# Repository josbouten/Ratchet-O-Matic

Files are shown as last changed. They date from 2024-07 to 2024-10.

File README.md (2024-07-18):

# Ratchet-O-Matic

This is Ratchet-O-Matic, a clock multiplier and clock divider.

While watching a video by Gary P. Hayes using a clock multiplier to ratchet some notes and playing with a Hydra synth (which has a knob for ratcheting on the front panel!) at my friend Macross' house I got inspired to make my own module that can ratchet, which I will call a ratcheteer. It has a second mode in which it can divide gate pulses (skip notes).

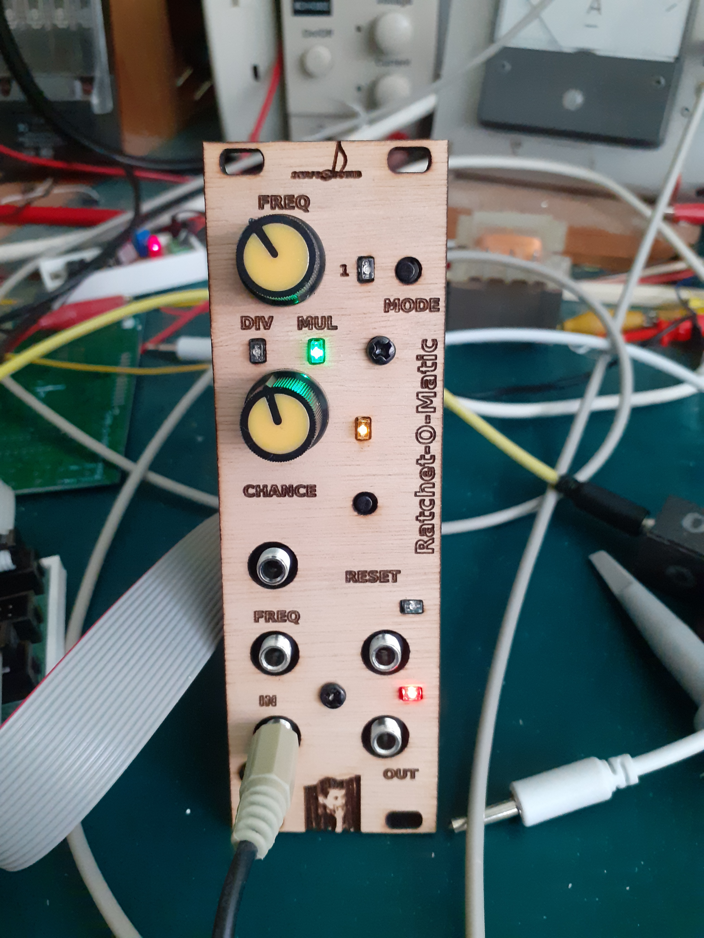
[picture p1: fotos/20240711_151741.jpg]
Ratchet-O-Matic ratcheteer


In this demo you can see and hear hand controlled ratcheting and ratcheting using a B960 sequencer to control the ratchet frequency and the odds to ratchet.
Also a short demo of dividing gates is shown.

https://www.youtube.com/watch?v=JYEgaoM7ovk

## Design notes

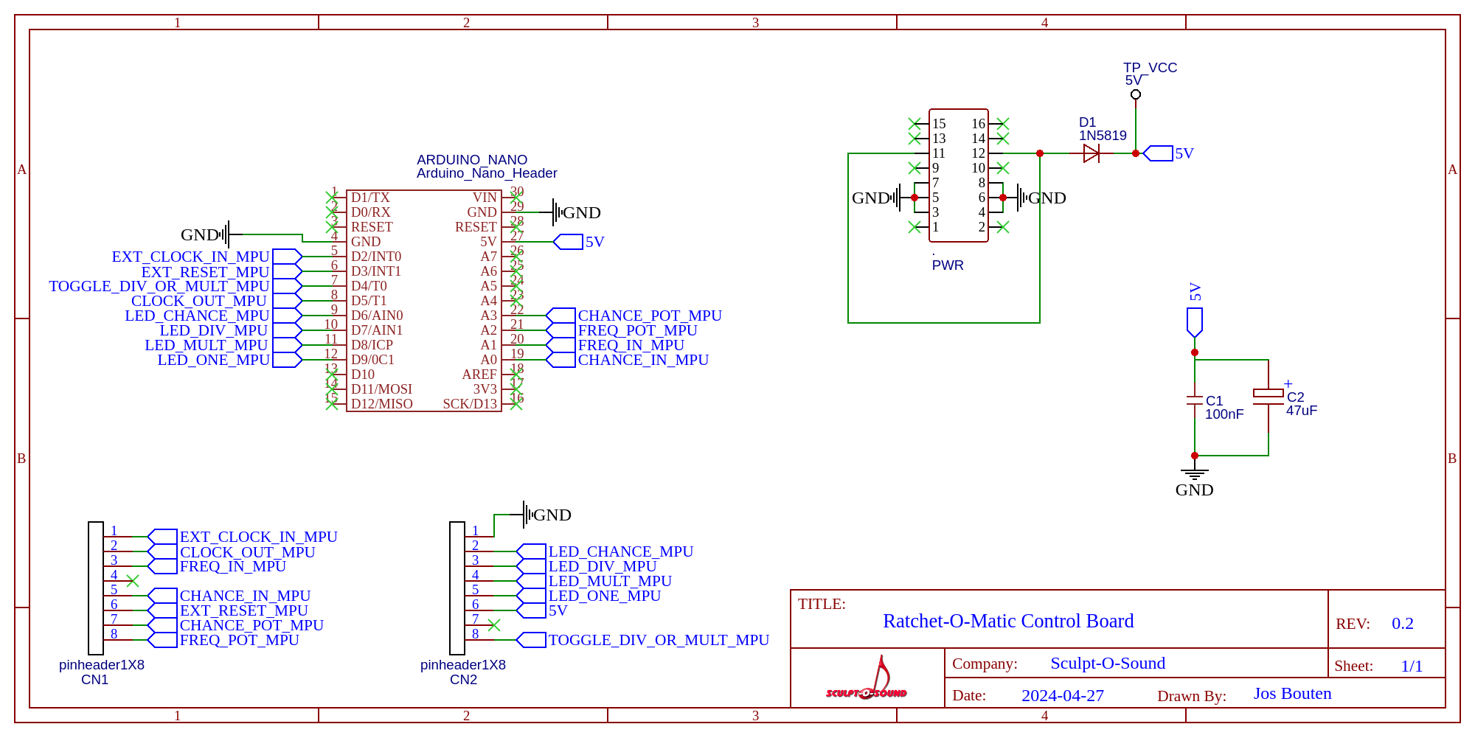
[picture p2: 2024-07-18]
schematics/Schematic_Ratchet-O-Matic-single-control-board-v0.2.png

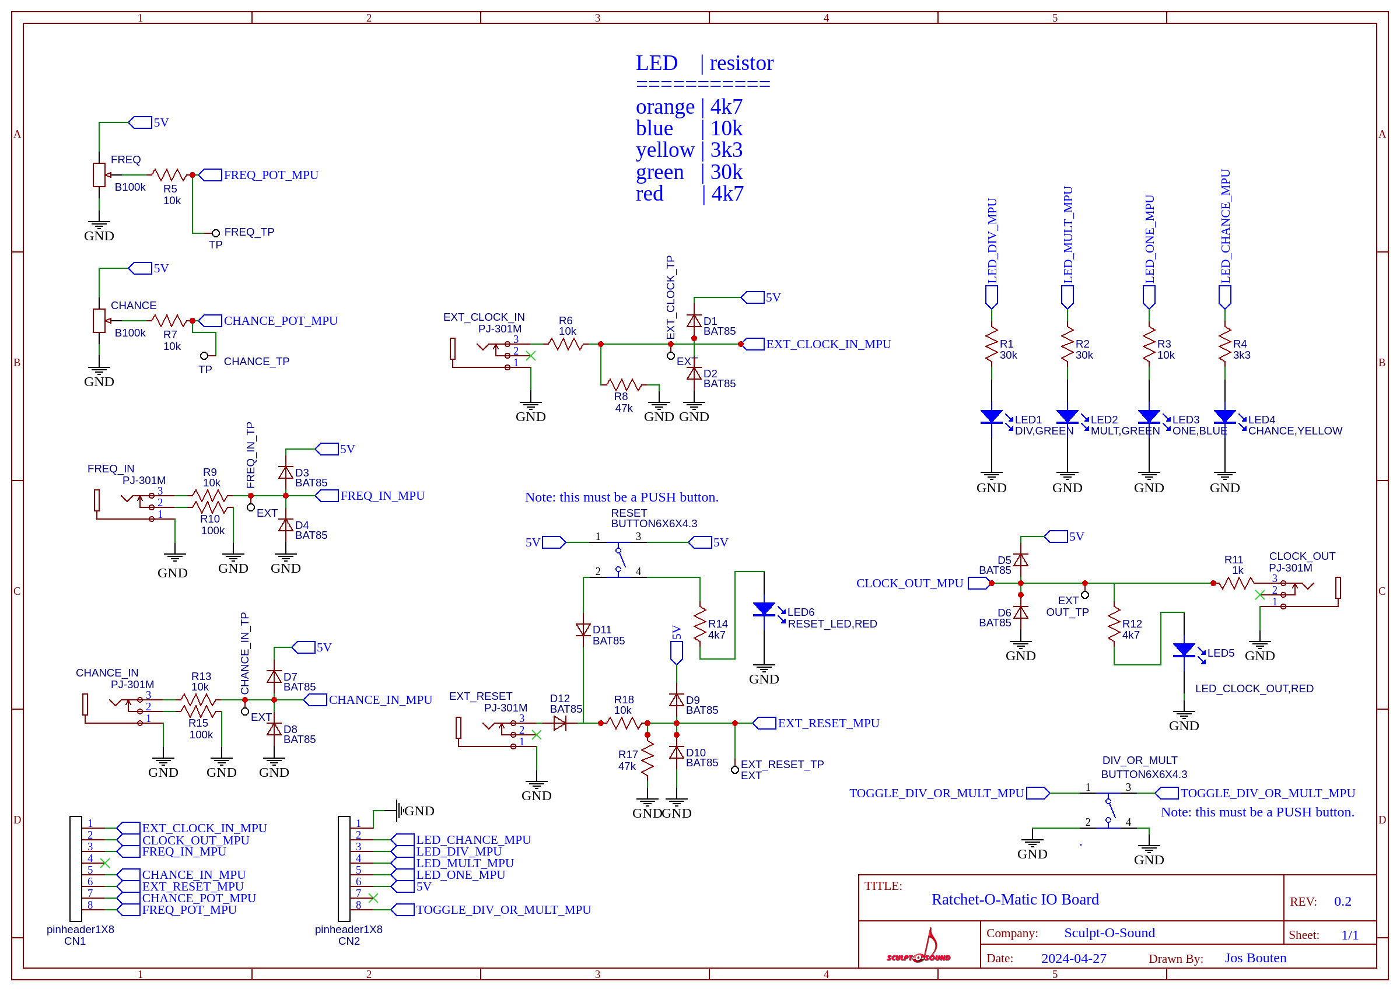
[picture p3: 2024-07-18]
schematics/Schematic_Ratchet-O-Matic-single-IO-board-v0.2.png

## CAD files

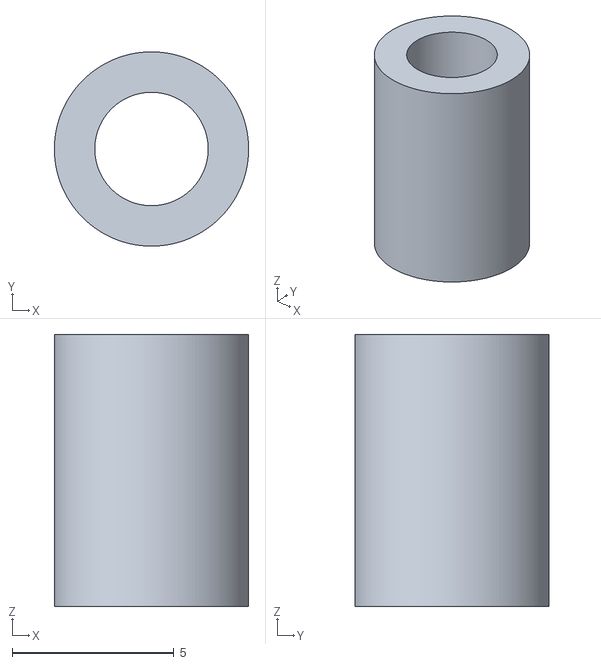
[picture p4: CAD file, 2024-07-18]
3D/afstandsbus_01.stl
6.00 x 6.00 x 8.40

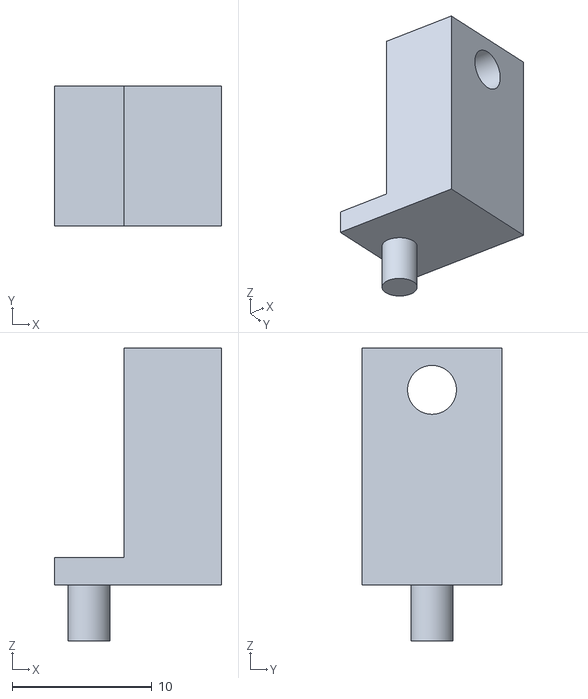
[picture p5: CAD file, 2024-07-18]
3D/bracket_05.stl
12.0 x 10.0 x 21.0

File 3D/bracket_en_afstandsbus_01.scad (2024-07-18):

// Steunbeugel voor de PCBs van de Ratchet-O-Matic.abs

$fn = 160;

as_lengte = 4; // mm.

opzet_blok_hoogte = 15;
opzet_blok_x = 7; 
opzet_blok_y = 10;
basis_height = 2;

module as() {
    diameter = 3.0;
    cylinder(h=as_lengte, r = diameter / 2, center=true);
}

module basis_links() {
    x = 12;
    y = 10;   
    cube([x, y, basis_height], center = true);
}


module opzet_blok() {
    cube([opzet_blok_x, opzet_blok_y, opzet_blok_hoogte], center = true);
}

module boorgat_links() {
    #translate([3, 0, 0]) rotate([0, 90, 0]) cylinder(h=opzet_blok_x, r=3.5 / 2.0, center = true);
}

module blokje_links() {
    translate([0, 0, as_lengte / 2]) as();
    translate([3.5, 0, as_lengte + basis_height / 2]) basis_links();
    x_verplaatsing = 6;
    translate([x_verplaatsing, 0, as_lengte + basis_height + opzet_blok_hoogte / 2]) opzet_blok();
}

module bracket() {
    difference() {
        blokje_links();
        boorgat_hoogte = as_lengte + basis_height + opzet_blok_hoogte - 3;
        echo("boorgat hoogte:", boorgat_hoogte);
        translate([3, 0, boorgat_hoogte]) boorgat_links();
    }
}

module afstandsbus() {
    difference() {
        cylinder(8.4, 6 / 2, 6 / 2);
        cylinder(8.4, 3.5 / 2, 3.5 / 2);
    }
}

module alles(a = 0, b = 0) {
    if (a == 1) {
        translate([20, 0, 0]) bracket();
    }
    if (b == 1) {
        afstandsbus();
    }
}

alles(1, 1);

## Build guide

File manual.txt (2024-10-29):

Ratchet-O-Matic
===============
There are 3 modes, DIV, MULT and MAX_MULT.
In DIV-mode the input gates are devided by a number.
This number is determined by the maximum value read from the FREQ-pot and the FREQ-CV input.
Whether any division is done depends on the highest value read from the CHANCE-pot and CHANCE CV-input.
This value is converted into a probability running from 0 to 1. A higher probability makes it more likely that
a gate signal will be generated.
The gate in frequency can be divide by 1, 2, 3, 4, 5, 6, 7, 8, 9 and 16.

In MULT-mode the input gates are multiplied by a factor 0, 1, 2, 3, 4 or 5.
This multiplication number is determined by the maximum value read from the FREQ-pot and the FREQ-CV input.
If the factor is 1 then the '1'-led will light up.

In MULT_MAX mode the number of ratchets varies at random from a minimum value set by the FREQ-knob
to a maximum value determined by the CV-input value.

Switching from DIV to MULT or DIV to MAX_MULT can be done by pressing the mode button once.
Switching from MAX_MULT to MULT and vv can be done in either mode by quickly double pressing the mode button.

Basic use of Ratchet-O-Matic
============================

0: make sure you have the following chain of modules prepared:
0a: an oscillator which produces a constant signal. Its pitch should be set. This oscillator is
0b: patched into a VCA (which has a gate input), which is
0c: patched into an amplifier with a speaker.
0d: prepare a clock source.

1: set the external clock to a slow pattern
   For beginners this makes it easier to discover the things Ratchet-O-Matic can do for you.
2a: connect the clock to the 'SHIFT'-input of the 960 sequencer,
2b: connect the clock output to the ‘clock in’ of the Ratchet-O-matic module,
2c: make sure the mode is set to ‘MUL’ (MULT-led is continuously lit) or 'MULT_MAX' (MULT-led will flash).
    MULT is the default mode when first switched on. After that the device will remember which
    state you last set it to.

3: connect the ‘gate out’ of Ratchet-O-Matic to the ‘gate’ of the VCA

4: choose the mode (MULT/DIV/MAX_MULT) using the mode button.

5: set a frequency with the FREQ-knob. Turned fully counterclockwise the frequency = 0,
   no gate signal pulse will be sent to the output.
   Turned fully clockwise, the frequency is 5 when in ratchet mode. In divide mode the frequency is 1/16
   The clock in frequency can be divide by 1, 2, 3, 4, 5, 6, 7, 8, 9 and 16 in DIV mode.
   The clock in frequency is multiplied by a factor 0, 1, 2, 3, 4 or 5. in (MAX_)MULT mode.
   When set to 1 the '1'-led will light up.

6: use the CHANCE-knob or connect a cv value to the chance-in input to set the odds that a ratchet or divided
   clock will be passed to the output. In MAX_MULT the chance pot and cv-value are ignored.

How to use Ratchet-O-Matic incombination with a 960 sequencer
=============================================================

0: make sure you have the following chain of modules prepared:
0a: an oscillator which produces a constant signal (either tone or noise),
0b: patched into a VCA (which has a gate input),
0c: patched into an amplifier with a speaker.
0d: prepare a clock source.

1: set the external clock to a slow pattern,

2a: connect the clock to the 'SHIFT'-input of the 960 sequencer,
2b: connect the clock output to the ‘clock in’ of the Ratchet-O-matic module,
2c: make sure the mode is set to ‘MUL’ = multiply, the LED should then light up,
That is the default mode, but the device will remember in what state you switched it off,
so you may have to set it to ‘MUL’,

3: connect the ‘gate out’ of Ratchet-O-Matic to the ‘gate’ of the VCA

4: Choose the MULT-mode using the mode button. The MULT-led should be lit continously.
   When the MULT-led is flashing you are in the MAX_MULT mode. Double click the button to
   return to the MULT mode.

5: press the “osc off” button of the 960. It should not run on its own oscillator,

6: connect a patch cable from the bottom row of the 960 to the ‘chance-in’ input of Ratchet-O-Matic,

7: connect a patch cable from the middle row of the 960 to the ‘freq-in’ input of Ratchet-O-Matic,

8: connect a patch cable from the top row of the 960 to the ‘V/Oct-in’ of the audio oscillator,

9a: set the bottom row chicken knob of the 960 to ‘X2’,
9b: set the pots of the bottom row of the 960 all far beyond the center position.
    This should set the odds for them to fire all the time high enough.
    The ‘Chance LED’ should be lit all the time,

10a: set the middle chicken knob to ‘X2’,
10b: set most of the pots of the middle row of the 960 below the center position and a few
     above the center position. Below a certain voltage no clock will be on the output, given a slightly
     higher voltage one clock pulse will reach the output. Higher voltages will result in ratcheting.
     The higher the voltage the more pulses will reach the output,
10c: when using a noise generator you can skip setting the 960 pots in the top row, otherwise choose
     set a tone sequence.

11: set the 'Chance knob' on Ratchet-O-Matic to 0, so that the odds are only determined
    by the input signal on the 'chance'-input,

12: set the 'freq knob' on Ratchet-O-Matic to 0, so that the number of ratchets is only
    determined by the input signal on the 'freq'-input. The number of gate pulses per step can
    be set using the potmeters to be 0 up to 5.

13a: Start with rather low ratchet settings and contrast them with rather high settings to find your bearing.
13b: Then fine tune and set the number of ratchets you like. Lower some of the odds pots so that not all
     notes are ratcheted.

How to get a random number of ratchets
======================================
Double click the mode button until the MULT-led flashes. You are in MAX_MULT mode now.
In this mode, the settings of the "freq"-knob determines the minimum number of
ratchets i.e. output gates. The maximum number of gates is determined by the CV value.

The lowest number of gates you can set when the knob is set to 0.
When set to 1 the '1'-led will light up to signal this. For higher values of the Potentiometers,
the '1'-led is off and the number of gates is 2 or more.

The chance knob and CV input are of no effect on the number of gate outs in this mode.

How to use Ratchet-O-Matic as a clock divider
=============================================
Make the same connections as above and set the mode to 'DIV' using the mode button.
Now the highest value of 'freq'-pot and 'freq-in' cv-value determines the division factor.
DIV can divide by 1, 2, 3, 4, 5, 6, 7, 8, 9 and 16. A value of 1 means that for each note a gate
os produced, so you should hear all notes. For higher values notes will be skipped. This can lead
to interesting polyrhythms.

Note:

1: the pots can produce a voltage between a maximum and a minimum value and the chicken
   knobs on the 960 determine in what range that is. Switching the chicken knob will
   change the range of all pots of the corresponding row.

2: when using the CV inputs, note that Ratchet-O-Matic chooses the highest value of the
   input and the corresponding knob value. This goes for Ratcheting or Division
   frequency and the odds settings.

2: when in MULT or DIV mode Ratchet-O-Matic chooses the highest value of the
   input and the corresponding knob value to determine the number of gates or the
   odds of producing a gate. In these modes Ratchet-O-Matic can be used without any CV inputs.
   In MAX_MULT however, a CV value on the FREQ-in is necessary. It will set the maximum count of
   ratchets while the FREQ-knob will set the minimum number of ratchets.

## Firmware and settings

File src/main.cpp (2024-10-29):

/*
  Ratchet-O-Matic by J.S. Bouten, 2024

  While watching a video by Gary P Hayes using a clock multiplier and playing with a Hydra synth
  at my friend Macross' house I got inspired to make a module that can ratchet (would that be a ratcheteer)?

  This is version 0.1 with one pot for chance and one for mult/div factor, 2 corresponding cv inputs,
  a reset button and reset input, a mult/div toggle button and one output.

  There are 2 modes, 'MULT' is for ratcheting and 'DIV' is for dividing the clockpulses.
  MULT can ratchet the clock by 1, 2, 3, 4 and 5.
  DIV can divide by 1, 2, 3, 4, 5, 6, 7, 8, 9 and 16.
  Feed a clock into the 'IN' jack and connect the 'OUT' with a sound source you want to either
  send that clock to unchanged or send a ratcheted clock or a divided clock.
  The maximum value of the Chance Pot and Chance IN is used to determine the odds that DIV or MULT does its thing.
  The Mode button allows for switching between the MULT and DIV mode. The setting will be stored in EEPROM so that
  the device will start up in the mode it was last used.
  The maximum value of the FREQ Pot and FREQ input is used to determine the number of ratchets or the division factor.
  The reset button and input can be used to reset the divider's counter.

  Note: the BLUE led will light up when the freq is set to 1 so that you can easily see that it is not something else ....
  The YELLOW led lights up when chance level is exceeded.
  The RED led shows the outgoing pulses.
  The GREEN leds signal MULT or DIV mode.

  The hardware accompanying this code can be found at https://github.com/josbouten/Ratchet-O-Matic

  July 15. 2024: v0.1
  - Initial build of DIV and MULT function.

  October 13. 2024: v0.2
  - Shifted scanning of potmeter from interrupt routine to main loop.
  - Allowed for freq value to be 0.

  October 28, 2024: v0.3
  - Added a mode accessible via double clicking the mode button when in MULT-mode.
    In this mode a random number of ratchets is produced where the freq-pot and CV-input
    determine the maximum number of output gates as a result of one input gate signal.
    The minimum output gates produced is 1.

*/
#include <Arduino.h>
#include "MillisDelay.hpp"

#define DEBUG
#define WRITE_TO_EEPROM
//#define INIT_EEPROM

// When using the device the 1st time, make sure the eeprom is
// filled from address 0:
// 1: define INIT_EEPROM
// 2: compile and run once
// 3: un-define INIT_EEPROM
// 4: compile and run as often as you like.

#include "Debug.hpp"

#include <TimerOne.h>
#include "LibPrintf.h"

#include "OneButton.h"
#include "RandomNumberGenerator.hpp"

#define EXT_CLOCK_IN    2 // This MUST be an intrerrupt enabled input; D2 ==> INT0
#define EXT_RESET_MPU   3 // This MUST be an interrrupt enabled input; D3 ==> INT1
#define TOGGLE_DIV_OR_MULT_MPU 4 // D4: button to toggle between multiply and divide function.
#define CLOCK_OUT       5 // D5
#define LED_CHANCE_MPU  6 // D6
#define LED_DIV_MPU     7 // D7
#define LED_MULT_MPU    8 // D8
#define LED_ONE_MPU     9 // D9

#define CHANCE_IN_MPU  A0 // Signal from chance potentiometer
#define FREQ_IN_MPU    A1 // Signal from frequency CV input.
#define FREQ_POT_MPU   A2 // Signal from frequency potentiometer
#define CHANCE_POT_MPU A3 // Signal from chance CV input.


#define OUT_HIGH true // Set to false when using an arduino output only. But if this is followed by a BJT, this must be inverted!
#define OUT_LOW (!OUT_HIGH)

// Define the number of rising clock signals on the ext clock input we use
// to compute the cycle time (inversely related to bpm) of the clock.
#define NR_OF_CYCLES 5

// Do we want to reset estimating the cycle time, this will take #cycles clock pulses
// each time we receive an external reset signal?
//#define RESTART_CLOCK_SPEED_ESTIMATION_ON_RESET

OneButton button(TOGGLE_DIV_OR_MULT_MPU); // Button has pull up resistor and is LOW when pushed.

#define INIT 0
#define DIV  1
#define ONE  2
#define MULT 3
#define MAX_MULT 4

#define NR_OF_LED_MODES 5
#ifdef DEBUG
  String mode_str[NR_OF_LED_MODES] = { "INIT", "DIV", "ONE", "MULT", "MAX_MULT" };
#endif

#define INITIAL_MULT_MODE MULT
byte oldMultMode;

const byte NR_OF_LEDS = 6;
byte allLeds[NR_OF_LEDS] = { LED_DIV_MPU, LED_MULT_MPU, LED_ONE_MPU, LED_CHANCE_MPU, EXT_RESET_MPU, CLOCK_OUT };
const byte NR_OF_TESTS = 2;

#include "LedTester.hpp"
#include "LedCluster.hpp"

LedTester ledTester(allLeds);

LedCluster ledCluster(LED_DIV_MPU, LED_MULT_MPU, LED_ONE_MPU);

LFSR_RandomNumberGenerator *randomNumberGenerator;

MillisDelay aliveDelay;
#define BUILT_IN_LED_INTERVAL_TIME 500 // time in mS
MillisDelay potmeterScanDelay;
#define POTMETER_SCAN_INTERVAL_TIME 100 // time in mS

#define NR_OF_MULT_POT_VALUES 6
byte potValues4Mult[NR_OF_MULT_POT_VALUES] = { 0, 1, 2, 3, 4, 5 };

#define NR_OF_DIV_POT_VALUES 11
byte potValues4Div[NR_OF_DIV_POT_VALUES] =  { 0, 1, 2, 3, 4, 5, 6, 7, 8, 9, 16 };

int getFraction(int nrOfValues, byte potValues[]) {
  // nrOfValues will be 0 ... NR_OF_FRACTIONS - 1 or 0 ... NR_OF_MULT_POT_VALUES - 1
  int maxVal = max(analogRead(FREQ_POT_MPU), analogRead(FREQ_IN_MPU));
  int index = map(maxVal, 0, 1024, 0, nrOfValues);
  //debug_print4("m: %d, i: %2d v:%2d\n", maxVal, index, potValues[index]);
  return(potValues[index]);
}

void getFraction(int nrOfValues, byte potValues[], byte *minValue, byte *maxValue) {
  // nrOfValues will be 0 ... NR_OF_FRACTIONS - 1 or 0 ... NR_OF_MULT_POT_VALUES - 1
  int minVal = analogRead(FREQ_POT_MPU);
  int minIndex = map(minVal, 0, 1024, 0, nrOfValues);
  int maxVal = analogRead(FREQ_IN_MPU);
  int maxIndex = map(maxVal, 0, 1024, 0, nrOfValues);
  *minValue = potValues[minIndex];
  *maxValue = potValues[maxIndex];
}


typedef struct SettingsObjType {
  volatile byte device_mode; // Either DIV, MULT or MAX_MULT, but never ONE.
  volatile byte dummy[3];    // Add dummy bytes until total size of struct is integer multiple of sizeof(MARKER)
} SettingsObjType_t ;

SettingsObjType_t settings;

#include <EEPROM.h>
#include "Eeprom.hpp"

#define FOUR_BITS 4

Eeprom eeprom;

int getFraction() {
    int frac;
    if (settings.device_mode == MULT) {
      frac = getFraction(NR_OF_MULT_POT_VALUES, potValues4Mult);
    } else {
      byte minValue, maxValue;
      if (settings.device_mode == MAX_MULT) {
        // Use the pot for the lower limit and the CV-value for the upper limit.
        getFraction(NR_OF_MULT_POT_VALUES, potValues4Mult, &minValue, &maxValue);
        // We limit frac to a range from 1 ... maxFrac.
        frac = randomNumberGenerator->getRandomNumber(minValue, maxValue + 1, FOUR_BITS);
      } else { // mode must be DIV
        frac = getFraction(NR_OF_DIV_POT_VALUES, potValues4Div);
      }
    }
    return(frac);
}

int getChanceValue(int nrOfValues) {
  // Use the maximum value of the potentiometer and the CV input value to determine the chance.
  // result will be [ 0 ... 100 ]
  int maxValue = max(analogRead(CHANCE_POT_MPU), analogRead(CHANCE_IN_MPU));
  long result = map(maxValue, 0, 1023, 0, nrOfValues);
  //debug_print2("chance: %ld\n", result);
  return(int(result));
}

//
// Vars and functions etc. for Timer1 (16 bits) which is used for a clock signal connected to INT0.
//

// Vars to be used with timer 1.
volatile unsigned long cycleTime = 750000L; // Time in microseconds.
volatile unsigned int newPeriodTime;
volatile bool outState = OUT_HIGH;
volatile int frac = 2;
volatile byte irqCnt = 0;
volatile unsigned long oldTime = micros();
volatile unsigned long thisTime;
volatile unsigned long sumTime = 0L;
volatile byte irqCounter = 0;
#ifdef DEBUG
  volatile bool led_builtin_state = true;
#endif

#define MIN_CHANCE_LEVEL 0
#define MAX_CHANCE_LEVEL 100

#define SEVEN_BITS 7

bool oddsInFavour() {
  // We want the chance level to increase when turning the potentiometer to the right.
  int chanceLevel = getChanceValue(100);
  if (randomNumberGenerator->getRandomNumber(MIN_CHANCE_LEVEL, MAX_CHANCE_LEVEL, SEVEN_BITS) < chanceLevel) {
    digitalWrite(LED_CHANCE_MPU, LED_ON);
    return(true);
  } else {
    digitalWrite(LED_CHANCE_MPU, LED_OFF);
    return(false);
  }
}

void timerInterrupt() {
  irqCnt++;
  digitalWrite(CLOCK_OUT, outState);
  outState = !outState;
  if (irqCnt > (2 * frac)) {
    Timer1.stop();
  }
}

void clockISR() { // Will respond to a rising edge on INT0
  Timer1.stop();
  // We measure the cycle time in MICRO seconds.
  thisTime = micros();
  // If there is an IRQ from INT0, then increment the counter.
  irqCounter++;
  sumTime += thisTime - oldTime;
  oldTime = thisTime;
  // We use the mean of several inter interrupt times as the cycle time.
  if (irqCounter > NR_OF_CYCLES) {
    cycleTime = sumTime / irqCounter;
    irqCounter = 0;
    sumTime = 0;
  }

  #ifdef DEBUG
    digitalWrite(LED_BUILTIN, led_builtin_state);
    led_builtin_state = !led_builtin_state;
  #endif

  frac = getFraction();
  // debug_print2("%d ", frac);
  if (frac == 0) {
    // No gate is send. The odds are of no importance, so the led is turned off.
    digitalWrite(CLOCK_OUT, OUT_LOW);
  } else {
    if (frac == 1) { // We pass the clock pulse unchanged.
        irqCnt = 0;
        // The period time will be in micro seconds.
        Timer1.setPeriod(cycleTime / 2);
        Timer1.start();
        // We start with a high output.
        digitalWrite(CLOCK_OUT, OUT_HIGH);
        // The next state will be LOW.
        outState = OUT_HIGH;
    } else { // For all values of frac > 1
      if (settings.device_mode != DIV) { // We are in MULT or MAX_MULT mode
        // We are multiplying the clock frequency of the 1st clock signal by starting
        // a fast timer and counting its cycles until we have seen enough. The clock may
        // be multiplied by a factor of 1 or higher.
        irqCnt = 0;
        // We start with a high output.
        digitalWrite(CLOCK_OUT, OUT_HIGH);
        // The next state will be LOW.
        outState = OUT_HIGH;
        // If the chance level is higher than some probability value then the odds are in
        // favour of ratcheting (producing more than 1 output gate during this clock cycle).
        if (settings.device_mode == MAX_MULT) {
          Timer1.setPeriod(cycleTime / 2 / frac);
        } else {
          if (oddsInFavour()) { // Yes, we can ratchet!
            Timer1.setPeriod(cycleTime / 2 / frac);
          } else {
            Timer1.setPeriod(cycleTime / 2);
          }
        }
        // The period time will be in micro seconds.
        Timer1.start();
      } else { // We are in DIV mode.
        // We are counting external clock pulses to divide their frequency.
        irqCnt++;
        // We leave it up to chance whether we divide or not.
        // If the chance level is higher than some probability number, then the odds are in
        // favour of producing an output gate.
        if (oddsInFavour()) {
          if (irqCnt >= frac) {
            irqCnt = 0;
            outState = OUT_HIGH;
            digitalWrite(CLOCK_OUT, OUT_HIGH);
            return;
          }
        }
        digitalWrite(CLOCK_OUT, OUT_LOW);
      }
    }
  }
}

void resetISR() {
  if (settings.device_mode == DIV) {
    // There must be at least one cycleTime between responses to external reset signals or a button push.
    #ifdef RESTART_CLOCK_SPEED_ESTIMATION_ON_RESET
      sumTime = 0;
      irqCounter = 0;
    #endif
    irqCnt = 0;
    Timer1.stop();
    outState = OUT_LOW;
    digitalWrite(CLOCK_OUT, OUT_LOW);
    // As soon as the next clockISR() occurs, the new output value is set synchronously to the clock
  }
}

void toggleBetweenDivAndMultModes() {
  // If the mult/div button was pressed,
  // toggle the settings.device_mode.
  if (settings.device_mode == DIV) {
    settings.device_mode = oldMultMode;
  } else {
    settings.device_mode = DIV;
  }
  eeprom.writeSettings();
  ledCluster.setMode(settings.device_mode);
}

void toggleBetweenMultModes() {
  // When in MULT or MAX_MULT mode, toggle between the two and update eeprom.
  if (settings.device_mode != DIV) {
    if (settings.device_mode == MULT) {
      settings.device_mode = MAX_MULT;
      oldMultMode = MAX_MULT;
      // We do not use the chance pot or CV value in this mode.
      // so the led will be lit all the time.
      digitalWrite(LED_CHANCE_MPU, LED_ON);
    } else {
      settings.device_mode = MULT;
      oldMultMode = MULT;
    }
    ledCluster.setMode(settings.device_mode);
    eeprom.writeSettings();
  }
}

void setup() {
  debug_begin(230400);
  debug_print("Begin of Setup()\n");
  // EEPROM
  eeprom = Eeprom(EEPROM.length());
  #ifdef INIT_EEPROM
    eeprom.resetStartAddress();
    settings.device_mode = MULT;
    if (eeprom.write(settings) < 0) {
      debug_print("Error writing data to eeprom. Data does not fit in eeprom.\n");
    } else {
      debug_print2("eeprom read  address after writing: %d\n", eeprom.getReadAddress());
      debug_print2("eeprom write address after writing: %d\n", eeprom.getWriteAddress());
    }
  #else
    if (eeprom.isEmpty()) {
      debug_print("Found empty EEPROM.");
      settings.device_mode = MULT;
      if (eeprom.write(settings) < 0) {
        debug_print("Error writing data to eeprom. Data does not fit in eeprom.\n");
      } else {
        debug_print2("eeprom read  address after writing: %d\n", eeprom.getReadAddress());
        debug_print2("eeprom write address after writing: %d\n", eeprom.getWriteAddress());
      }
    } else {
      eeprom.read(&settings);
    }
    debug_print3("Mode (at setup): %d %s\n", settings.device_mode, mode_str[settings.device_mode].c_str());
    // Show that all leds work.
    ledTester.test();
    if (settings.device_mode != DIV) {
      oldMultMode = settings.device_mode;
    } else {
      oldMultMode = INITIAL_MULT_MODE;
    }
    if (settings.device_mode == MAX_MULT) {
      // We do not use the chance pot or CV value in this mode.
      // so the led will be lit all the time.
      digitalWrite(LED_CHANCE_MPU, LED_ON);
    }

    pinMode(LED_BUILTIN, OUTPUT);

    // Potentiometers
    //
    pinMode(FREQ_IN_MPU, INPUT);
    // The first ADC value is unreliable. Let's get it over with.
    analogRead(FREQ_IN_MPU);

    pinMode(FREQ_POT_MPU, INPUT);
    // The first ADC value is unreliable. Let's get it over with.
    analogRead(FREQ_POT_MPU);

    pinMode(CHANCE_IN_MPU, INPUT);
    // The first ADC value is unreliable. Let's get it over with.
    analogRead(CHANCE_IN_MPU);

    pinMode(CHANCE_POT_MPU, INPUT);
    // The first ADC value is unreliable. Let's get it over with.
    analogRead(CHANCE_POT_MPU);

    pinMode(LED_CHANCE_MPU, OUTPUT);

    // Clock inputs.
    //
    pinMode(EXT_CLOCK_IN, INPUT);  // D2/INT0
    pinMode(EXT_RESET_MPU, INPUT); // D3/INT1

    // Define some Toggle buttons for DIV/MULTIPLY and
    // add some LEDs to show their status.
    //

    // Attach functions to the buttons.
    button.attachClick(toggleBetweenDivAndMultModes);

    button.attachDoubleClick(toggleBetweenMultModes);

    // Now set the LEDs according to the defaults.
    ledCluster.setMode(settings.device_mode);
    debug_print3("Setting mode to %d %s\n", settings.device_mode, mode_str[settings.device_mode].c_str());

    // Initialize CycleTime before starting the ISR routine.
    oldTime = micros();

    randomNumberGenerator = new LFSR_RandomNumberGenerator(analogRead(A4)); // Get an unused analog input (electrically floating) as a random seed value.

    // Attach IRQs once all the rest has been initialized
    debug_print2("Attaching interrupt 0 to pin D%d for external clock.\n", EXT_CLOCK_IN);
    attachInterrupt(digitalPinToInterrupt(EXT_CLOCK_IN), clockISR, RISING);
    pinMode(CLOCK_OUT, OUTPUT); // Setting output after setting counter modes as advised by the ATmega321P datasheet.

    debug_print2("Attaching interrupt 1 to pin D%d for external reset.\n", EXT_RESET_MPU);
    attachInterrupt(digitalPinToInterrupt(EXT_RESET_MPU), resetISR, RISING);

    outState = OUT_LOW;
    frac = getFraction();
    debug_print2("Frac: %d\n", frac);
    Timer1.initialize(cycleTime / 2 / frac);
    if (settings.device_mode != DIV) { // Mode is MULT or MAX_MULT
      Timer1.start();
    } else {
      Timer1.stop();
    }
    digitalWrite(CLOCK_OUT, OUT_HIGH);
    Timer1.attachInterrupt(timerInterrupt);
  #endif

  aliveDelay = MillisDelay(BUILT_IN_LED_INTERVAL_TIME);
  aliveDelay.start();
  potmeterScanDelay = MillisDelay(POTMETER_SCAN_INTERVAL_TIME);
  potmeterScanDelay.start();
  debug_print("End of Setup()\n");
}

#ifdef INIT_EEPROM
void loop() {
    delay(1000);
    debug_print("Recompile and upload with undefined INIT_EEPROM\n");
    if ((sizeof(SettingsObjType) % sizeof(MARKER)) != 0) {
      debug_print("Error! sizeof(SettingsObjType) should be integer multiple of sizeof(MARKER)!\n");
    }
  }
#else
  void loop() {
    // Show that we are alive.
    if (aliveDelay.justFinished()) {
      digitalWrite(LED_BUILTIN, !digitalRead(LED_BUILTIN));
      aliveDelay.start();
    }
    // A getFraction call is included here so that when there is a slow clock
    // or there is no clock a value for frac is determined and the ONE-led is
    // set accordingly.
    if (potmeterScanDelay.justFinished()) {
      frac = getFraction();
      // debug_print2("%d ", frac);
      if (frac == 1) {
        ledCluster.setMode(ONE);
      }
       else {
        ledCluster.setMode(settings.device_mode);
      }
      potmeterScanDelay.start();
    }
    // Respond to button clicks.
    button.tick();
    // Update the eeprom when necessary.
    eeprom.tick();
    // Update the 3 mode leds when necessary.
    ledCluster.tick();
  }
#endif

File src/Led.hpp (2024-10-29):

#ifndef _LED_HPP
#define _LED_HPP

#include <Arduino.h>

#define LED_OFF 0
#define LED_ON 1
#define LED_SLOW_FLASH 2
#define LED_FLASH 3
#define LED_FAST_FLASH 4
#define LED_REDICULOUS_FLASH 5

class Led {

    private:
        byte pinNumber;
        byte state;

        bool onOffState;
        unsigned long onTime[6] = { 0L, 1000L, 500L, 250L, 130L, 25L };
        unsigned long oldTime;

    public:

        Led() {}

        Led(byte pinNumber, byte initialState): pinNumber(pinNumber), state(initialState) {
            oldTime = millis();
            onOffState = false;
        }

        void setState(byte someState) {
            state = someState;
        }

        void tick() {
            if (state < LED_SLOW_FLASH) {
                // We do not flash.
                if (state == LED_OFF) { // The led is switched off.
                    digitalWrite(pinNumber, LOW); // Switch led OFF.
                } else { // The led is lit continuously.
                    digitalWrite(pinNumber, HIGH); // Switch led ON.
                }
            } else {
                // We flash.
                if ((millis() - oldTime) > onTime[state]) {
                    oldTime = millis();
                    onOffState = !onOffState;
                    digitalWrite(pinNumber, onOffState);
                }
            }
        }
};

#endif
